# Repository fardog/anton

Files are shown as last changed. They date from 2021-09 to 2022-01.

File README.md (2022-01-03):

# anton

A quick and dirty air sensor which submits data directly to an [InfluxDB][]
v1 instance, without auth.

I built this because the west coast is on fire, and I ran out of [Luftdaten][]
sensor parts. It's not pretty or full featured but it works.

[InfluxDB]: https://docs.influxdata.com/influxdb/v1.8/
[Luftdaten]: https://sensor.community/

## Requirements

Hardware:

* An ESP development board for ESP8266 or ESP32, such as:
  * NodeMCUv3 or similar ESP8266 platform
  * Lolin32 or similar ESP32 platform
* A particulate sensor, one of:
  * [ZH03B][]
  * [PMS7003][]; Only the PMS7003 has been tested, but other PMSX003 sensors may
    work.
* (Optional) A multisensor:
  * [BME680][] sensor and breakout board; configured for i2c
* (Optional) A CO₂ sensor:
  * [MH-Z19B][]

[ZH03B]: https://www.winsen-sensor.com/sensors/dust-sensor/zh3b.html
[PMS7003]: http://www.plantower.com/en/content/?110.html
[BME680]: https://www.bosch-sensortec.com/products/environmental-sensors/gas-sensors-bme680/
[MH-Z19B]: https://www.winsen-sensor.com/sensors/co2-sensor/mh-z19b.html

Software:

* InfluxDB v1.8

Wire the ZH03B as follows:

* Pin1: `VU`
* Pin2: `Ground`
* ESP8266
  * Pin4: `D4`
  * Pin5: `D3`
* ESP32
  * Pin4: `TX2` (`GPIO17`)
  * Pin5: `RX2` (`GPIO16`)

Or the PMS7003 as follows:

* Pin1: `VU`
* Pin3: `Ground`
* ESP8266
  * Pin7: `D3`
  * Pin9: `D4`
* ESP32
  * Pin7: `TX2` (`GPIO17`)
  * Pin9: `RX2` (`GPIO16`)

(Optional) Wire the BME680 as follows:

* VCC: `3v3`
* GND: `Ground`
* ESP8266
  * SCL: `D1`
  * SDA: `D2`
* ESP32
  * SCL: `SCL` (`GPIO22`)
  * SDA: `SDA` (`GPIO21`)

(Optional) Wire the MH-Z19B as follows, tested only on ESP32:

* VCC: `VU`
* GND: `Ground`
* ESP8266
  * TXD: `D5`
  * RXD: `D6`
* ESP32:
  * TXD: `GPIO18`
  * RXD: `GPIO19`

A 3D printable case for Anton is available at [PrusaPrinters][]. **Note:** the
case fits the ZH03B and ESP8266; for PMS7003 or ESP32, you're on your own right
now, but I'll make one in the future.

[PrusaPrinters]: https://www.prusaprinters.org/prints/40746-case-for-anton-air-quality-influxdb

## Installation

This is built using [PlatformIO][]; refer to their docs on building/uploading.

[PlatformIO]: https://platformio.org/

## Setup

Once uploaded and booted, a wireless network called `anton` will be
created; join this network and you will be directed to a captive portal for
configuration.

## Measurements

Measurements are submitted to the configured database as a measurement named
`particulate_matter`. It will contain the following tags:

* `node` the sensor name
* `location` (optional) the sensor location

…and the following fields containing integer values:

* `p1_0` PM1.0
* `p2_5` PM2.5
* `p10_0` PM10
* `aqi` EPA [AQI][]

[AQI]: https://www.airnow.gov/aqi/aqi-basics/

…and the following string values:

* `aqi_contributor` the primary AQI contributor (highest value); the string will
  match the measurement name, e.g. `p2_5`

**Note:** currently only PM10 and PM2.5 are accounted for in AQI measurements,
following the EPA standard.

**Note:** if the AQI cannot be determined, either due to overflow or other
error, it will be omitted from the InfluxDB submission.

### Multisensor

If you have the optional multisensor connected, the following additional fields
fields will be sent; all are integers unless noted:

* `temperature_c` (float) °C
* `temperature_c_raw` (float) °C, uncompensated
* `humidity` %rh
* `pressure` hPa
* `gas_resistance` Ohm
* `iaq` EPA [IAQ][].
* `iaq_accuracy` IAQ accuracy; see notes
* `co2_equiv` Equivalent CO₂ PPM
* `co2_equiv_accuracy` Equivalent CO₂ accuracy; see notes
* `breath_voc` (float) Breath VOC
* `breath_voc_accuracy` Breath VOC Accuracy; see notes

[IAQ]: https://www.epa.gov/indoor-air-quality-iaq/introduction-indoor-air-quality

**Note:** Various `accuracy` values are provided by the Bosch Sensortec
[BSEC][bsec] library, which have the following meaning ([source][bsec-src]):

* `0` sensor is stabilizing
* `1` readings were too stable to define references
* `2` currently calibrating
* `3` calibrated

[bsec-src]: https://community.bosch-sensortec.com/t5/Question-and-answers/What-does-the-IAQ-accuracy-mean-in-BSEC/qaq-p/5935

### Dedicated CO₂ Sensor

If you have the optional dedicated CO₂ sensor connected, the following
additional integer fields will be sent:

* `co2` PPM

**Note:** when using the optional dedicated CO₂ sensor, you must provide a base
calibration every few weeks. This can be done from the dashboard's calibration
page, and should be initiated when background levels are low. If indoors it's
recommended to open a window and allow good air circulation for several minute
before performing the calibration. This calibration takes 20 minutes.

## Administration

Once configured, a webserver is exposed on port 80 which can be used to view
sensor values, update firmware, change configuration, and reboot or reset the
sensor.

## Changelog

See [CHANGELOG](./CHANGELOG.md).

## Acknowledgements

This was quick to implement due to the following excellent libraries:

* [@ShaggyDog18/SD_ZH03B](https://github.com/ShaggyDog18/SD_ZH03B)
* [@tobiasschuerg/InfluxDB-Client-for-Arduino](https://github.com/tobiasschuerg/InfluxDB-Client-for-Arduino)
* [@prampec/IotWebConf](https://github.com/prampec/IotWebConf)
* [@BoschSensortec/BSEC-Arduino-library][bsec]
* [@fu-hsi/PMS](https://github.com/fu-hsi/PMS)
* [@Erriez/ErriezMHZ19B](https://github.com/Erriez/ErriezMHZ19B)

## License

The code contained in this repo is released under the GNU [GPL-3.0](./LICENSE).

Building this project requires pulling in the various submodules under the `lib`
directory, each of which has their own license; of note the [BSEC][bsec] library
provided by [Bosch Sensortec][bosch] has a closed source binary blob provided
under a unique license which you must abide to use this software.

[bsec]: https://github.com/BoschSensortec/BSEC-Arduino-library
[bosch]: https://www.bosch-sensortec.com/software-tools/software/bsec/

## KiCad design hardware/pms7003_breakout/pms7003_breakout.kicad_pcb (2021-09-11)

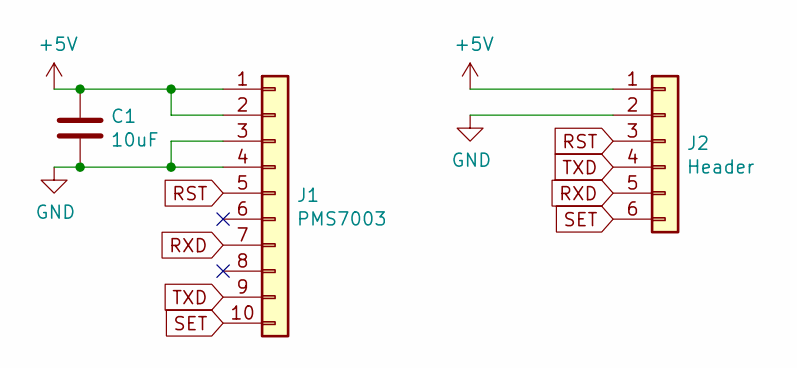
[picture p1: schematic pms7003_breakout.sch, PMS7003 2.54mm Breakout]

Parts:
C1: 10uF; C_0805_2012Metric_Pad1.18x1.45mm_HandSolder
J1: PMS7003; PinHeader_2x05_P1.27mm_Vertical
J2: Header; PinHeader_1x06_P2.54mm_Vertical

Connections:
+5V: C1.1, J1.1, J1.2, J2.1
GND: C1.2, J1.3, J1.4, J2.2
RST: J1.5, J2.3
RXD: J1.7, J2.5
SET: J1.10, J2.6
TXD: J1.9, J2.4

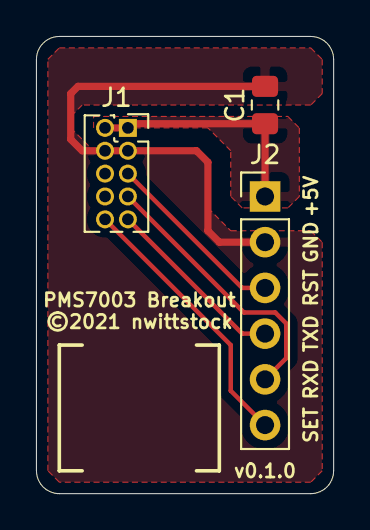
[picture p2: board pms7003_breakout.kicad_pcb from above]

Board: 2 copper layers, 16.5 x 25.4 mm, 3 parts (0 on the bottom side), 6 nets.

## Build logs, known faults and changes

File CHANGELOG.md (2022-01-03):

# Changelog

Changes which are not backwards compatible will be listed here. Anton is under
active development and does not have a fixed feature set, nor does it have
version numbers yet. For now, changes will be listed by date.

## 2022-01-03

To report more accurate temperatures, the following changes were made:

* Temperature fields are now floats
* A compile-time temperature offset may be provided, which is used by the BSEC
  library to perform its calculations.

### Temperature Fields

Temperature fields are now floats; in previous versions they were integers,
which loses a lot of precision when dealing in Celsius. To avoid conflicts
with existing databases, fields were renamed/added:

* `temperature` is now `temperature_c`
* `temperature_c_raw` is the uncompensated temperature; direct from the sensor

**Note:** `temperature_c_raw` is _not_ the same as "`temperature_c` ignoring
offset", but rather the raw reading from the sensor itself. If you needed the
previous equivalent `temperature` you should take `temperature_c` and remove the
compiled offset from it, although there shouldn't be much use for this value.

### Compile-time Temperature Offset

When compiling Anton firmware, you may define the float value
`BSEC_TEMPERATURE_OFFSET_C` which will be passed to the underlying [BSEC][bsec]
library to determine the temperature offset that should be used. The default
value of `4.0` works well for various 3D printable cases, and you may override
it for your application as necessary.

**Note:** This value is _subtracted_ from the values that are read; you will
almost always wish to specify a positive value here.

## 2021-12-12

Move to Bosch Sensortec's [BSEC][bsec] library for the BME680, which improves
accuracy of the temperature/humidity readings as well as provides equivalent CO₂
values without the dedicated sensor. However this brings additional license
restrictions which you should [view and accept][bosch] before using.

[bsec]: https://github.com/BoschSensortec/BSEC-Arduino-library
[bosch]: https://www.bosch-sensortec.com/software-tools/software/bsec/

## 2021-09-25

Does away with pin/UART configurations and makes them compile time. Also added
CO₂ sensor options. This caused a revision of the configuration options, and you
will need to reconfigure the sensor after flashing.

## 2021-07-04

Moves from [WifiManager][] to [IotWebConf][]. *This is a backwards incompatible
change.* You will need to reconfigure the sensor after upgrading.

[WifiManager]: https://github.com/tzapu/WiFiManager
[IotWebConf]: https://github.com/prampec/IotWebConf

## 2020-10-22

Moved from the deprecated `SPIFFS` to the still-maintained `LittleFS`. *This is
a backwards incompatible change.* You will need to reconfigure the sensor after
upgrading.

## 2020-10-03

Earlier versions of Anton submitted values to InfluxDB as floats; this has been
corrected to use integer values. Updating will require you to either use a new
database or rewrite your existing one.

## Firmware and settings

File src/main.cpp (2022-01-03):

#include <Arduino.h>

#include <AQI.h>

#include <IotWebConf.h>
#include <IotWebConfTParameter.h>

#ifdef ESP8266
#include <ESP8266HTTPUpdateServer.h>
#elif defined(ESP32)
// For ESP32 IotWebConf provides a drop-in replacement for UpdateServer.
#include <IotWebConfESP32HTTPUpdateServer.h>
#endif

#include "strings.h"

#include "Anton.h"
#include "reporters/Reporter.h"
#include "reporters/InfluxDB_Reporter.h"
#include "sensors/AirSensor.h"
#include "sensors/ZH03B_AirSensor.h"
#include "sensors/PMS_AirSensor.h"
#include "sensors/EnvironmentSensor.h"
#include "sensors/BME680_EnvironmentSensor.h"
#include "sensors/CO2Sensor.h"
#include "sensors/MHZ19B_CO2Sensor.h"
#include "util.h"

#ifndef GIT_REV
#define GIT_REV "Unknown"
#endif

#define STRING_LEN 128

#define CONFIG_VERSION "v3.0"
#define PRODUCT_NAME "anton"
#define DEFAULT_PASSWORD "anton-system"

#ifndef BSEC_TEMPERATURE_OFFSET_C
#define BSEC_TEMPERATURE_OFFSET_C 4.0
#endif

// pins
#ifdef ESP8266
#define PARTICULATE_RX D3
#define PARTICULATE_TX D4
// TODO: reevaluate these
#define CO2_RX D5
#define CO2_TX D6
#elif defined(ESP32)
#define PARTICULATE_UART 2
#define CO2_UART 1
#define UART_1_RX 18
#define UART_1_TX 19
#endif

// constants initialized at setup
char influxdbURL[200] = "";

// callbacks
void wifiConnected();

DNSServer dnsServer;
WebServer server(80);

#ifdef ESP8266
ESP8266HTTPUpdateServer httpUpdater;
#elif defined(ESP32)
HTTPUpdateServer httpUpdater;
#endif

#ifdef ESP8266
#define ANTON_PLATFORM "ESP8266"
#elif defined(ESP32)
#define ANTON_PLATFORM "ESP32"
#endif

IotWebConf iotWebConf(PRODUCT_NAME, &dnsServer, &server, DEFAULT_PASSWORD, CONFIG_VERSION);

iotwebconf::ParameterGroup sensorGroup = iotwebconf::ParameterGroup("sensorGroup", "Reporting");
iotwebconf::TextTParameter<STRING_LEN> sensorName =
    iotwebconf::Builder<iotwebconf::TextTParameter<STRING_LEN>>("sensorName")
        .label("Sensor Name")
        .defaultValue("anton-default")
        .build();
iotwebconf::TextTParameter<STRING_LEN> sensorLocation =
    iotwebconf::Builder<iotwebconf::TextTParameter<STRING_LEN>>("sensorLocation")
        .label("Sensor Location")
        .defaultValue("")
        .build();

iotwebconf::ParameterGroup influxdbGroup = iotwebconf::ParameterGroup("influxdbGroup", "InfluxDB");
iotwebconf::TextTParameter<STRING_LEN> influxdbHost =
    iotwebconf::Builder<iotwebconf::TextTParameter<STRING_LEN>>("influxdbHost")
        .label("Host")
        .defaultValue("influxdb")
        .build();
iotwebconf::IntTParameter<uint16_t> influxdbPort =
    iotwebconf::Builder<iotwebconf::IntTParameter<uint16_t>>("influxdbPort")
        .label("Port")
        .defaultValue(8086)
        .min(1)
        .max(65535)
        .step(1)
        .placeholder("8086")
        .build();
iotwebconf::TextTParameter<STRING_LEN> influxdbDatabase =
    iotwebconf::Builder<iotwebconf::TextTParameter<STRING_LEN>>("influxdbDatabase")
        .label("Database Name")
        .defaultValue("anton")
        .build();

static const char particleSensorValues[][STRING_LEN] = {"zh03b", "pms7003"};
static const char particleSensorNames[][STRING_LEN] = {"Winsen ZH03B", "Plantower PMS7003"};
iotwebconf::ParameterGroup particleSensorGroup = iotwebconf::ParameterGroup("particleSensorGroup", "Particulate Sensor");
iotwebconf::CheckboxTParameter particleSensorEnable =
    iotwebconf::Builder<iotwebconf::CheckboxTParameter>("particleSensorEnable")
        .label("Enabled")
        .defaultValue(false)
        .build();
iotwebconf::SelectTParameter<STRING_LEN> particleSensor =
    iotwebconf::Builder<iotwebconf::SelectTParameter<STRING_LEN>>("particleSensor")
        .label("Sensor")
        .optionValues((const char *)particleSensorValues)
        .optionNames((const char *)particleSensorNames)
        .optionCount(sizeof(particleSensorValues) / STRING_LEN)
        .nameLength(STRING_LEN)
        .defaultValue("zh03b")
        .build();

static const char vocSensorValues[][STRING_LEN] = {"bme680"};
static const char vocSensorNames[][STRING_LEN] = {"Bosch BME680"};
iotwebconf::ParameterGroup vocSensorGroup = iotwebconf::ParameterGroup("vocSensorGroup", "VOC Sensor");
iotwebconf::CheckboxTParameter vocSensorEnable =
    iotwebconf::Builder<iotwebconf::CheckboxTParameter>("vocSensorEnable")
        .label("Enabled")
        .defaultValue(false)
        .build();
iotwebconf::SelectTParameter<STRING_LEN> vocSensor =
    iotwebconf::Builder<iotwebconf::SelectTParameter<STRING_LEN>>("vocSensor")
        .label("Sensor")
        .optionValues((const char *)vocSensorValues)
        .optionNames((const char *)vocSensorNames)
        .optionCount(sizeof(vocSensorValues) / STRING_LEN)
        .nameLength(STRING_LEN)
        .defaultValue("zh03b")
        .build();

iotwebconf::ParameterGroup co2SensorGroup = iotwebconf::ParameterGroup("co2SensorGroup", "CO2 Sensor");
iotwebconf::CheckboxTParameter co2SensorEnable =
    iotwebconf::Builder<iotwebconf::CheckboxTParameter>("co2SensorEnable")
        .label("Enabled")
        .defaultValue(false)
        .build();
static const char co2SensorValues[][STRING_LEN] = {"mhz19b"};
static const char co2SensorNames[][STRING_LEN] = {"Winsen MH-Z19B"};
iotwebconf::SelectTParameter<STRING_LEN> co2SensorSelect =
    iotwebconf::Builder<iotwebconf::SelectTParameter<STRING_LEN>>("co2SensorSelect")
        .label("Sensor")
        .optionValues((const char *)co2SensorValues)
        .optionNames((const char *)co2SensorNames)
        .optionCount(sizeof(co2SensorValues) / STRING_LEN)
        .nameLength(STRING_LEN)
        .defaultValue("mhz19b")
        .build();

Stream *airSensorSerial = nullptr;
AirSensor *airSensor = nullptr;
Reporter *reporter = nullptr;
EnvironmentSensor *environmentSensor = nullptr;
Stream *co2SensorSerial = nullptr;
CO2Sensor *co2Sensor = nullptr;
Anton *anton = nullptr;

void resetAll()
{
  iotWebConf.getSystemParameterGroup()->applyDefaultValue();
  iotWebConf.getWifiParameterGroup()->applyDefaultValue();
  sensorGroup.applyDefaultValue();
  influxdbGroup.applyDefaultValue();
  particleSensorGroup.applyDefaultValue();
  vocSensorGroup.applyDefaultValue();
  co2SensorGroup.applyDefaultValue();
  iotWebConf.saveConfig();
  ESP.restart();
}

void hardReset()
{
  util::clearEEPROM();
  ESP.restart();
}

void renderIndexPage(char *buf, Anton *anton)
{
  AirData ad = anton->airData();
  EnvironmentData ed = anton->environmentData();
  CalculatedAQI aqi = anton->aqi();
  CO2Data co2 = anton->co2Data();

  int lastMeasured = -1;
  if (ad.timestamp > 0)
  {
    lastMeasured = (millis() - ad.timestamp) / 1000;
  }

  int reported = -1;
  if (anton->lastReported() > 0)
  {
    reported = (millis() - anton->lastReported()) / 1000;
  }

  String lastStatus = anton->lastErrorMessage();
  if (lastStatus.equals(""))
  {
    lastStatus = "SUCCESS";
  }

  sprintf(
      buf,
      serverIndex,
      lastMeasured,
      reported,
      lastStatus.c_str(),
      ad.p1_0,
      ad.p2_5,
      ad.p10_0,
      util::rnd(aqi.value),
      aqi.pollutant,
      util::rnd(ed.tempC),
      util::rnd(ed.humPct),
      util::rnd(ed.iaq),
      co2.ppm,
      millis() / 1000,
      sensorName.value(),
      influxdbURL,
      GIT_REV,
      ANTON_PLATFORM);
}

void handleRoot()
{
  // -- Let IotWebConf test and handle captive portal requests.
  if (iotWebConf.handleCaptivePortal())
  {
    // -- Captive portal request were already served.
    return;
  }

  if (anton)
  {
    char buf[2048];
    renderIndexPage(buf, anton);
    server.send(200, "text/html", buf);
  }
  else
  {
    server.send(200, "text/html", serverUnconfigured);
  }
}

void handleGetCalibrate()
{
  server.send(200, "text/html", calibrationPage);
}

void handlePostCalibrate()
{
  String co2Success = String("NOT PRESENT");
  if (co2Sensor)
  {
    if (co2Sensor->calibrate())
    {
      co2Success = String("REQUESTED");
    }
    else
    {
      co2Success = String("FAILED");
    }
  }

  char buf[2048];
  sprintf(buf, calibrationResultPage, co2Success.c_str());
  server.send(200, "text/html", buf);
}

void setup()
{
  Serial.begin(115200);
  Serial.printf("setup: starting version %s\n", GIT_REV);

  sensorGroup.addItem(&sensorName);
  sensorGroup.addItem(&sensorLocation);
  iotWebConf.addParameterGroup(&sensorGroup);

  influxdbGroup.addItem(&influxdbHost);
  influxdbGroup.addItem(&influxdbPort);
  influxdbGroup.addItem(&influxdbDatabase);
  iotWebConf.addParameterGroup(&influxdbGroup);

  particleSensorGroup.addItem(&particleSensorEnable);
  particleSensorGroup.addItem(&particleSensor);
  iotWebConf.addParameterGroup(&particleSensorGroup);

  vocSensorGroup.addItem(&vocSensorEnable);
  vocSensorGroup.addItem(&vocSensor);
  iotWebConf.addParameterGroup(&vocSensorGroup);

  co2SensorGroup.addItem(&co2SensorEnable);
  co2SensorGroup.addItem(&co2SensorSelect);
  iotWebConf.addParameterGroup(&co2SensorGroup);

  iotWebConf.setWifiConnectionCallback(&wifiConnected);
  iotWebConf.setWifiConnectionTimeoutMs(60000);

  iotWebConf.setupUpdateServer(
      [](const char *updatePath)
      { httpUpdater.setup(&server, updatePath); },
      [](const char *userName, char *password)
      { httpUpdater.updateCredentials(userName, password); });

  iotWebConf.init();

  server.on("/", handleRoot);
  server.on("/config", []
            { iotWebConf.handleConfig(); });
  server.onNotFound([]()
                    { iotWebConf.handleNotFound(); });

  server.on("/calibrate", handleGetCalibrate);
  server.on("/calibrate-confirm", HTTP_POST, handlePostCalibrate);
  server.on("/reset", HTTP_GET, []()
            {
              Serial.println("http: serving reset");
              server.sendHeader("Connection", "close");
              server.send(200, "text/html", resetPage);
            });
  server.on("/reboot", HTTP_POST, []()
            {
              Serial.println("http: serving reboot");
              server.sendHeader("Connection", "close");
              server.send(200, "text/plain", "rebooting");
              ESP.restart();
            });
  server.on("/reset-confirm", HTTP_POST, []()
            {
              Serial.println("http: serving reset confirm");
              server.sendHeader("Connection", "close");
              server.send(200, "text/plain", "resetting");
              resetAll();
            });
  server.on("/hard-reset-confirm", HTTP_POST, []()
            {
              Serial.println("http: serving hard reset confirm");
              server.sendHeader("Connection", "close");
              server.send(200, "text/plain", "resetting");
              hardReset();
            });

  sprintf(influxdbURL, "http://%s:%d", influxdbHost.value(), influxdbPort.value());
  Serial.printf("setup: influxdb url: %s\n", influxdbURL);

  // set up reporter
  InfluxDB_Reporter *DB = new InfluxDB_Reporter(sensorName.value(),
                                                sensorLocation.value(),
                                                influxdbURL,
                                                influxdbDatabase.value());
  reporter = DB;

  if (particleSensorEnable.value())
  {
#ifdef ESP8266
    airSensorSerial = util::getSerial(PARTICULATE_RX, PARTICULATE_TX);
#elif defined(ESP32)
    airSensorSerial = util::getSerial(PARTICULATE_UART);
#endif

    if (strcmp(particleSensor.value(), "zh03b") == 0)
    {
      Serial.println("setup: starting ZH03B particle sensor on serial");
      ZH03B_AirSensor *ZH = new ZH03B_AirSensor(*airSensorSerial);
      airSensor = ZH;
    }
    else if (strcmp(particleSensor.value(), "pms7003") == 0)
    {
      Serial.println("setup: starting PMS7003 particle sensor on serial");
      PMS_AirSensor *PMS = new PMS_AirSensor(*airSensorSerial);
      airSensor = PMS;
    }
    else
    {
      Serial.printf("setup: invalid particle sensor type: %s\n", particleSensor.value());
    }
  }

  if (vocSensorEnable.value())
  {
    Serial.println("setup: starting BME680 VOC sensor on I2C (default pins)");
    Wire.begin();
    BME680_EnvironmentSensor *BME = new BME680_EnvironmentSensor(Wire, BSEC_TEMPERATURE_OFFSET_C);
    environmentSensor = BME;
  }

  if (co2SensorEnable.value())
  {
#ifdef ESP8266
    co2SensorSerial = util::getSerial(CO2_RX, CO2_TX);
#elif defined(ESP32)
    co2SensorSerial = util::getSerial(CO2_UART, 9600, SERIAL_8N1, UART_1_RX, UART_1_TX);
#endif
    co2Sensor = new MHZ19B_CO2Sensor(co2SensorSerial);
  }

  anton = new Anton(reporter, airSensor, co2Sensor, environmentSensor);
}

void wifiConnected()
{
  Serial.println("setup: wifi connected");
}

void loop()
{
  iotWebConf.doLoop();
  anton->loop();
}

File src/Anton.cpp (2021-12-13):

#include <Arduino.h>
#include "Anton.h"

Anton::Anton(Reporter *reporter,
             AirSensor *airSensor,
             CO2Sensor *co2Sensor,
             EnvironmentSensor *environmentSensor,
             uint16_t timeBetweenMeasurements)
    : _reporter(reporter),
      _airSensor(airSensor),
      _co2Sensor(co2Sensor),
      _environmentSensor(environmentSensor),
      _states{
          {StateId::STARTUP, 0, 0, StateId::WAKE_SENSORS},
          {StateId::WAKE_SENSORS, 0, 0, StateId::WARM_UP},
          {StateId::WARM_UP, 30000, 0, StateId::SAMPLE_PARTICULATE},
          {StateId::SAMPLE_PARTICULATE, 0, 30000, StateId::SAMPLE_CO2},
          {StateId::SAMPLE_CO2, 0, 30000, StateId::SAMPLE_ENVIRONMENT},
          {StateId::SAMPLE_ENVIRONMENT, 0, 10000, StateId::SLEEP_SENSORS},
          {StateId::SLEEP_SENSORS, 0, 10000, StateId::REPORT},
          {StateId::REPORT, 0, 30000, StateId::SLEEP},
          {StateId::SLEEP, timeBetweenMeasurements, 0, StateId::WAKE_SENSORS},
      }
{
  _state = _states[0];
}

Anton::~Anton() {}

void Anton::loop()
{
  unsigned long now = millis();

  if (_state.timeout > 0 && now > _lastTransition + _state.timeout)
  {
    Serial.printf("state %d timed out; moving to next state\n", _state.state);
    _stateFailed[_state.state] = true;
    _nextState();
    return;
  }

  if (_airSensor)
    _airSensor->loop();
  if (_co2Sensor)
    _co2Sensor->loop();
  if (_environmentSensor)
    _environmentSensor->loop();

  if (now < _stateStart)
    return;

  switch (_state.state)
  {
  case STARTUP:
    _startup();
    break;
  case WAKE_SENSORS:
    _wakeSensors();
    break;
  case WARM_UP:
    _warmUp();
    break;
  case SAMPLE_PARTICULATE:
    _sampleParticulate();
    break;
  case SAMPLE_CO2:
    _sampleCO2();
    break;
  case SAMPLE_ENVIRONMENT:
    _sampleEnvironment();
    break;
  case SLEEP_SENSORS:
    _sleepSensors();
    break;
  case REPORT:
    _report();
    break;
  case SLEEP:
    _sleep();
    break;
  }
}

void Anton::_nextState()
{
  Serial.printf("state change: %d -> %d, delaying %dms\n", _state.state, _state.next, _state.delay);
  _stateStart = millis() + _state.delay;
  _lastTransition = _stateStart;
  _state = _states[_state.next];
  _stateFailed[_state.state] = false;
}

void Anton::_retry(uint16_t delay)
{
  Serial.printf("retrying state %d, delaying %dms\n", _state.state, delay);
  _stateStart = millis() + delay;
}

void Anton::_startup()
{
  _nextState();
}

void Anton::_wakeSensors()
{
  if (!_airSensor)
  {
    _nextState();
    return;
  }

  if (_airSensor->wake())
  {
    _nextState();
  }
  else
  {
    Serial.println("failed to wake air sensor");
  }
}

void Anton::_warmUp()
{
  Serial.println("warming up");
  _nextState();
}

void Anton::_sampleParticulate()
{
  if (_airSensor)
  {
    if (_airSensor->getAirData(&_airData))
    {
      Serial.printf("Particulate: PM1.0, PM2.5, PM10=[%d %d %d]\n",
                    _airData.p1_0,
                    _airData.p2_5,
                    _airData.p10_0);

      _nextState();
    }
  }
  else
  {
    _nextState();
  }
}

void Anton::_sampleCO2()
{
  if (_co2Sensor)
  {
    if (_co2Sensor->getCO2Data(&_co2Data))
    {
      _nextState();
    }
  }
  else
  {
    _nextState();
  }
}

void Anton::_sampleEnvironment()
{
  if (_environmentSensor)
  {
    if (_environmentSensor->getEnvironmentData(&_environmentData))
    {
      Serial.printf("Environment: %.2f°C, %.2f%%rh, IAQ %.2f(%d), %.2fhPa, %.2fOhm, %.2fCO₂, %.2fVOC\n",
                    _environmentData.tempC,
                    _environmentData.humPct,
                    _environmentData.iaq,
                    _environmentData.iaqAccuracy,
                    _environmentData.pressure,
                    _environmentData.gasResistance,
                    _environmentData.co2Ppm,
                    _environmentData.breathVoc);
      _nextState();
    }
    else
    {
      Serial.printf("environment failed: %s\n", _environmentSensor->getLastError().c_str());
    }
  }
  else
  {
    _nextState();
  }
}

void Anton::_sleepSensors()
{
  if (!_airSensor)
  {
    _nextState();
    return;
  }

  if (_airSensor->sleep())
  {
    _nextState();
  }
}

void Anton::_report()
{
  AirData *ad = nullptr;
  EnvironmentData *ed = nullptr;
  CalculatedAQI *aqi = nullptr;
  CO2Data *co2 = nullptr;

  if (_airSensor && !_stateFailed[SAMPLE_PARTICULATE])
  {
    ad = &_airData;
    if (calculateAQI(_airData, &_aqi))
    {
      aqi = &_aqi;
    }
  }

  if (_environmentSensor && !_stateFailed[SAMPLE_ENVIRONMENT])
  {
    ed = &_environmentData;
  }

  if (_co2Sensor && !_stateFailed[SAMPLE_CO2])
  {
    co2 = &_co2Data;
  }

  if (_reporter->report(ad, aqi, ed, co2))
  {
    _lastErrorMessage = "";
    _lastReported = millis();

    _nextState();

    return;
  }

  _lastErrorMessage = _reporter->getLastErrorMessage();
  Serial.printf("failed to report: %s\n", _lastErrorMessage.c_str());
  _retry(3000);
}

void Anton::_sleep()
{
  Serial.println("sleeping");
  _nextState();
}

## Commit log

2020-09-14 don't submit failed readings
    [main.cpp]
2020-09-16 delay before first read, reset on failed sensor wake
    [main.cpp]
2020-09-23 add EPA AQI calculation to reported statistics (#1)
    * add aqi calculation
    * better
    * show aqi on index page, submit sample correctly
    * public aqi-cpp
    [main.cpp]
2020-10-07 Create sensor abstraction (#4)
    * create an abstraction for air sensors
    * move into lib directory
    * use non-client handling delay within server
    * remove extra sleep
    * fewer changes
    * missed one
    [main.cpp]
2020-10-08 Use AirData struct for interfaces (#6)
    * move sensors out of external lib folder
    * use airdata struct for interfaces
2020-10-21 add BME680 environment sensor (#9)
    * add bme680 sensor
    * make gas temp, millis configurable
    * report integer values
    * update README
    * remove altitude utility
    * update index page
    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
2021-07-04 fix pin comparison, update bme680 lib
    [main.cpp]
2021-07-04 migrate to Iotwebconf from WifiManager (#8)
    * move to iotwebconf; first pass, untested
    * handle configuration redirect
    * add back reset pages
    * fix building under latest platformio
    * fixes
    * fixes, pre-update reorg
    * update to latest iotwebconf, new config format
    * fixes, working
    * rename variables to style
    * more renaming
    * hard reset, update readme, fix formatting
    [main.cpp, util.cpp]
2021-07-05 cleanup: pin conversion, fix index page, more utils (#12)
    * cleanup: pin conversion, fix index page, more utils
    cleanup after the last few direct-to-main commits, which were to
    get things working again on various iterations of sensors I've
    built.
    * allow any pin for serial why not
    * make conversion to pin input better
    * move some things to utils that didn't require global context
    * fix the index page having nonsense values on it, and include
    more values
    * logging fixes
    [main.cpp, util.cpp]
2021-07-06 add pms7003 particulate sensor (#13)
    * add pms7003 particulate sensor
    * update readme for merging
    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
2021-07-07 ESP32 support (#14)
    * ESP32 support
    * fix readme
    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
    [main.cpp, util.cpp]
2021-09-11 Plantower PMS7003 breakout dev board (#16)
    * pms7003 breakout board
    * remove nested folder
    * add version to silkscreen
    [pms7003_breakout.kicad_pcb, pms7003_breakout.sch]
2021-09-23 Refactor (#17)
    * add taskscheduler
    * wip refactor
    * handle all states, retries, timeouts
    * remove module that didn't pan out
    * remove global variables, fix index page
    * fix initialization of Anton class
    * add note to README
    [Anton.cpp]
2021-09-26 CO₂ Sensor, supporting Winsen MH-Z19B (#18)
    * add mhz19b submodule
    * prototype co2 sensor
    * add lang and charset to pages
    * fix calibration confirm route
    * require co2 sensor to be enabled; fixed to U0
    * hard code pins; web config isn't worth the extra code
    * move strings to header
    * add co2 to reporter
    * don't send failed states
    * fix build on esp8266
    * rename misc
    * subscript
    * typo
    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
    [Anton.cpp]
2021-09-29 fix accidental fallthrough on environment sensor
    [Anton.cpp]
2021-09-29 apply a fixed offset to BME680 temperature
    this is by no means a complete fix, but how far this value is off
    implies we can't just trust whatever values the sensor returns without
    some calibration/adjustment.
2021-12-13 Use Bosch BSEC library for BME680 (#20)
    * use arduino bsec library
    * remove unused module
    * update modules in README
    * update iotwebconf to fix esp8266
    * update readme with notes on bsec library
    * update README for new fields
    * update changelog
    [Anton.cpp]
2021-12-13 fix reported pressure and gas resistances
2022-01-03 report temperature as float; specify temperature offset (#22)

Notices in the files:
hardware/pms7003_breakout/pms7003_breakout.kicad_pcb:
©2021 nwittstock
